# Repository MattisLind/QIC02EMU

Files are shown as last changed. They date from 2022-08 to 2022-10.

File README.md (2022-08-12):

# QIC02EMU

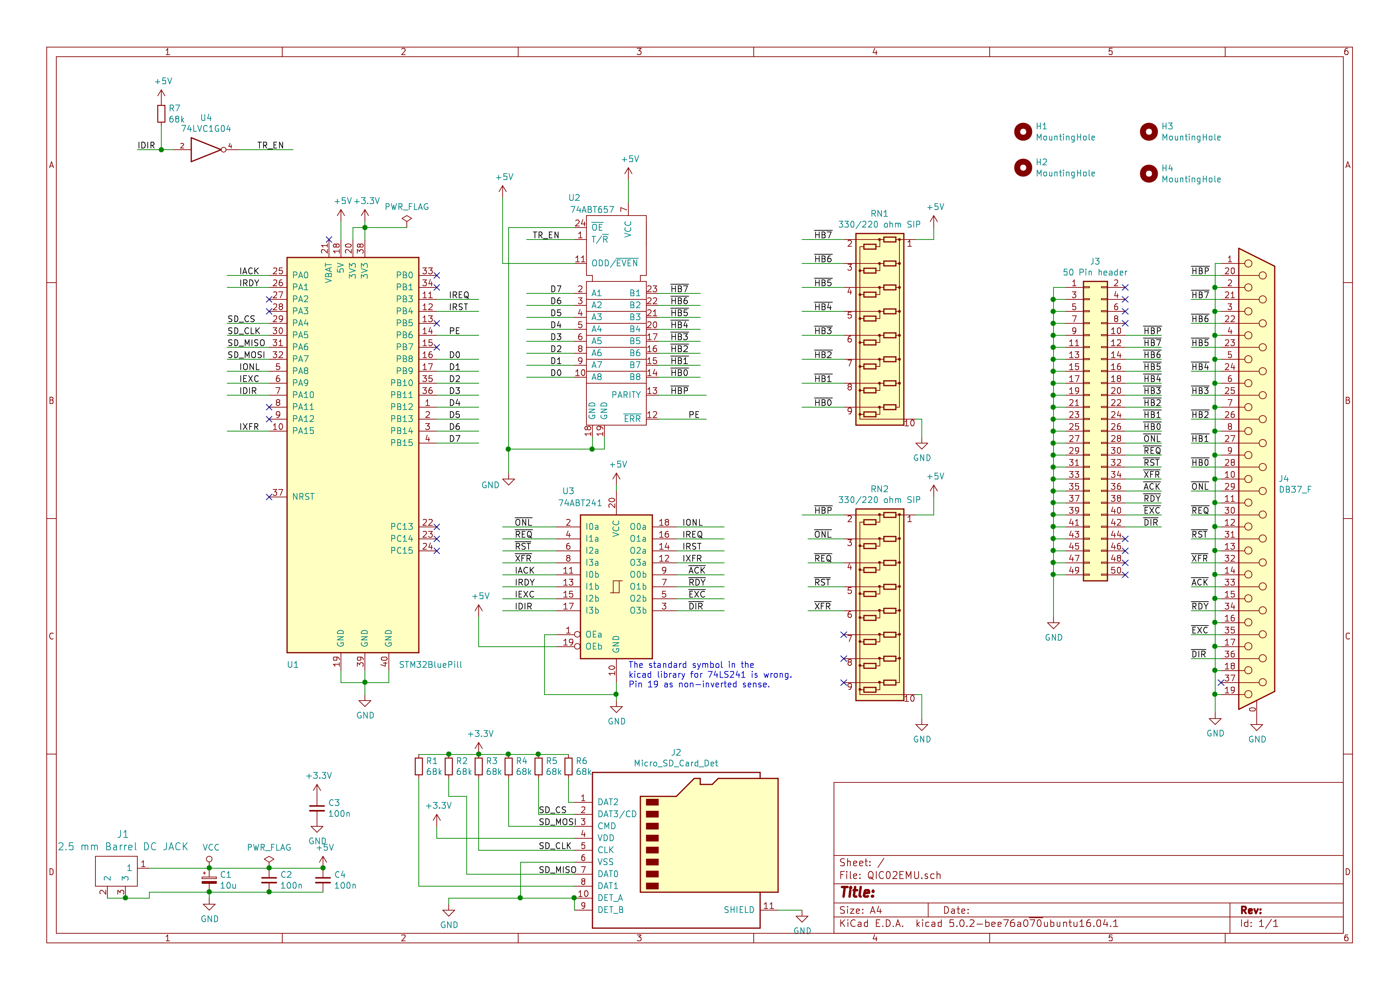
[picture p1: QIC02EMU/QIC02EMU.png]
Schematic


Device that is supposed to emulate a generic QIC-02 tape drive or specifically the IBM6157 tape drive. The IBM 6157 contains a Cipher 450 tape drive. But has a 37 pin DUSB interface cable rather than the 50 pin IDC type connector.

The card is supposed to plug directly into the IBM RT PC 6157 streaming tape controller board without using any cable.

Initially only reading of tape will be supported but later on writing will be implemented.

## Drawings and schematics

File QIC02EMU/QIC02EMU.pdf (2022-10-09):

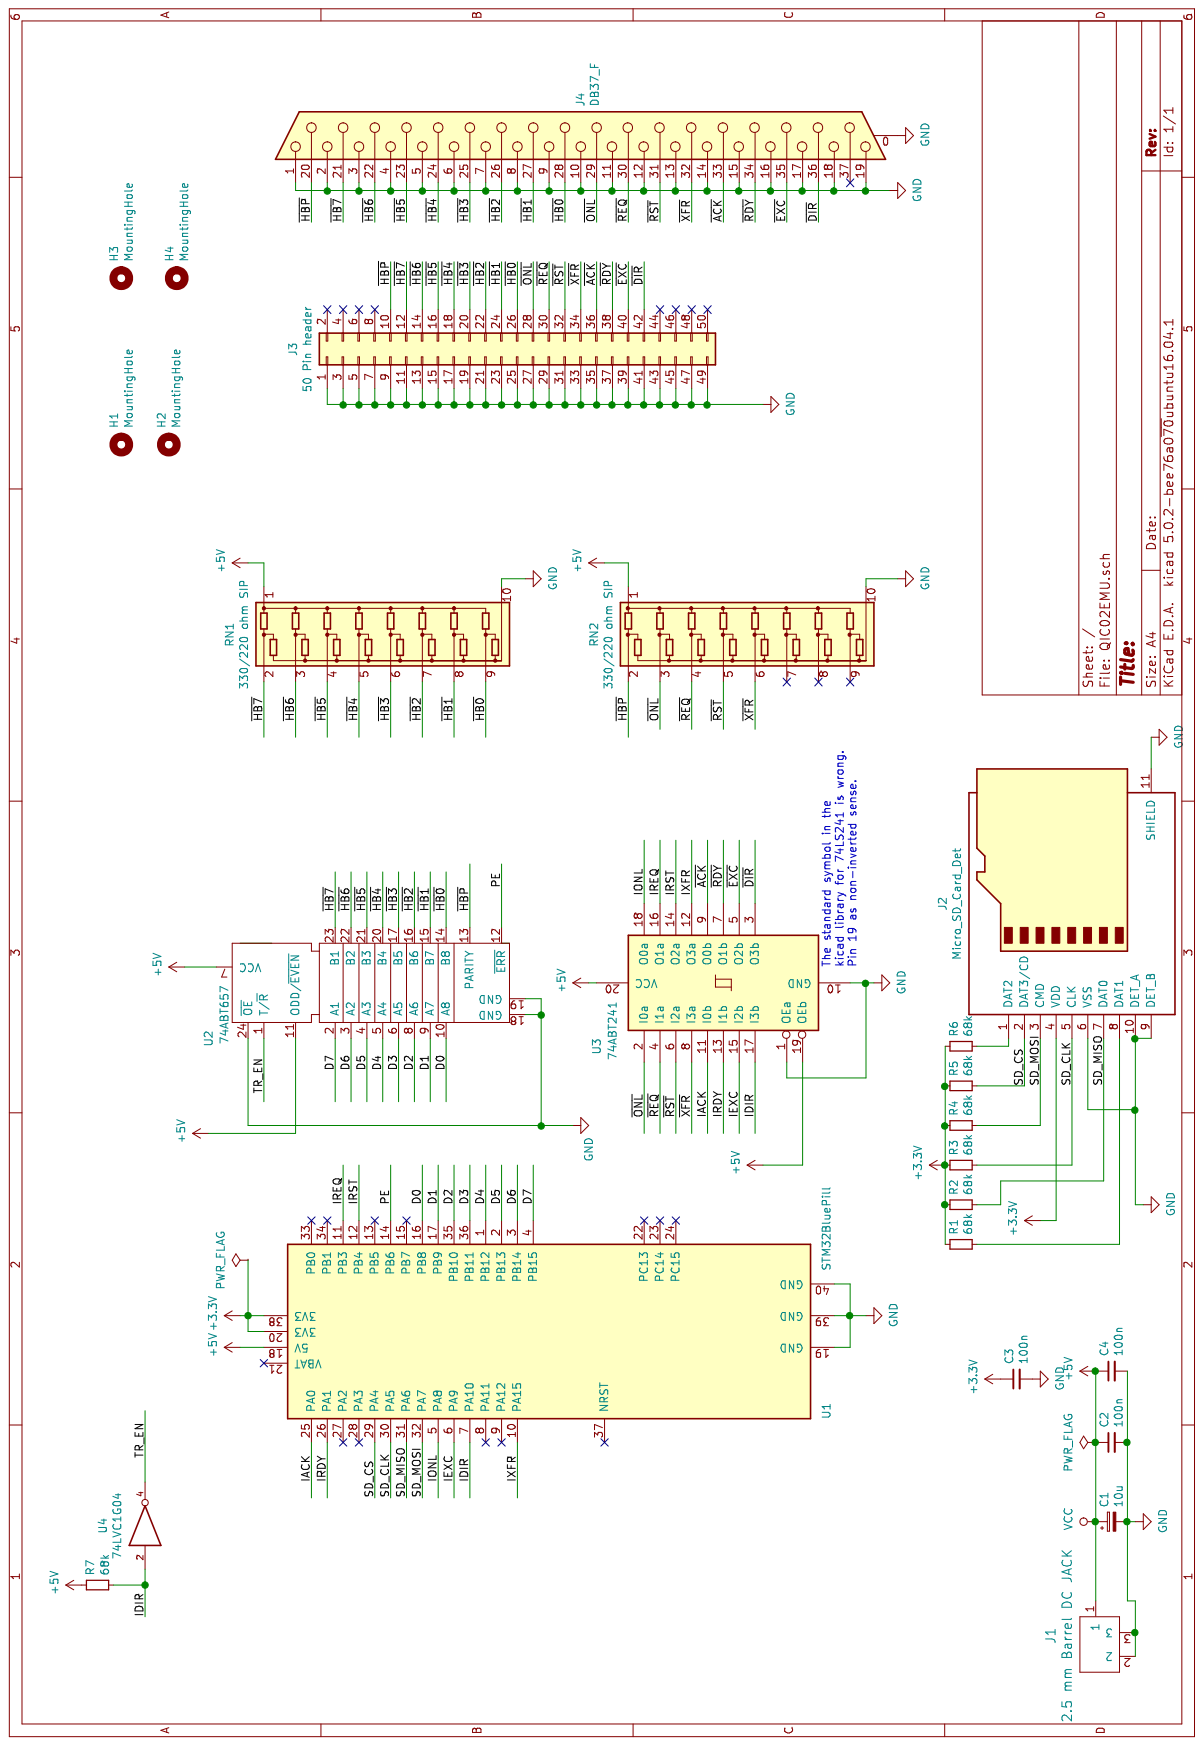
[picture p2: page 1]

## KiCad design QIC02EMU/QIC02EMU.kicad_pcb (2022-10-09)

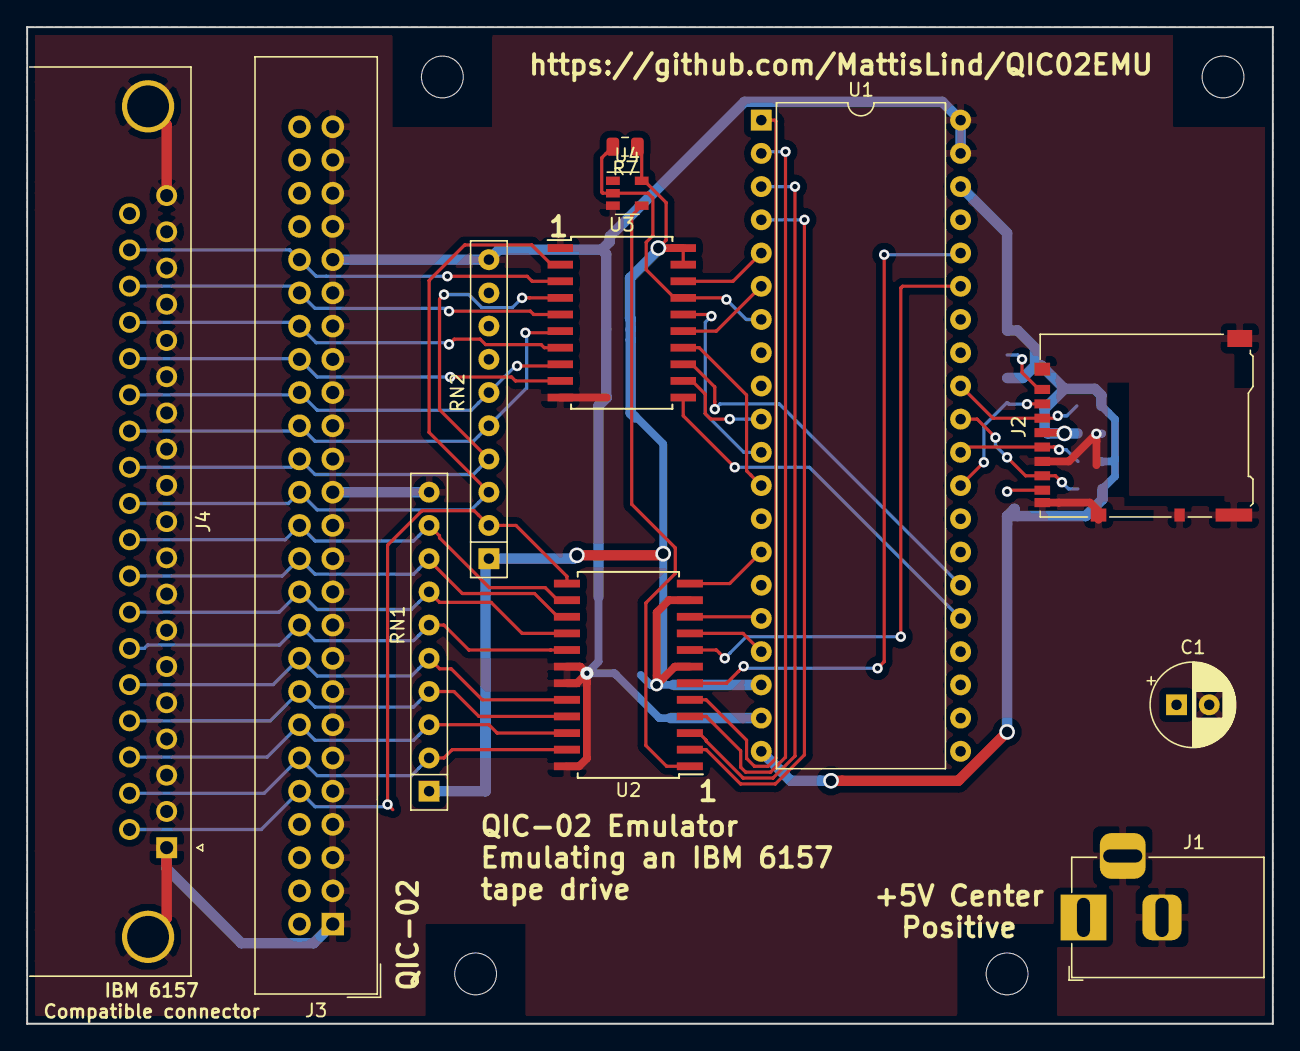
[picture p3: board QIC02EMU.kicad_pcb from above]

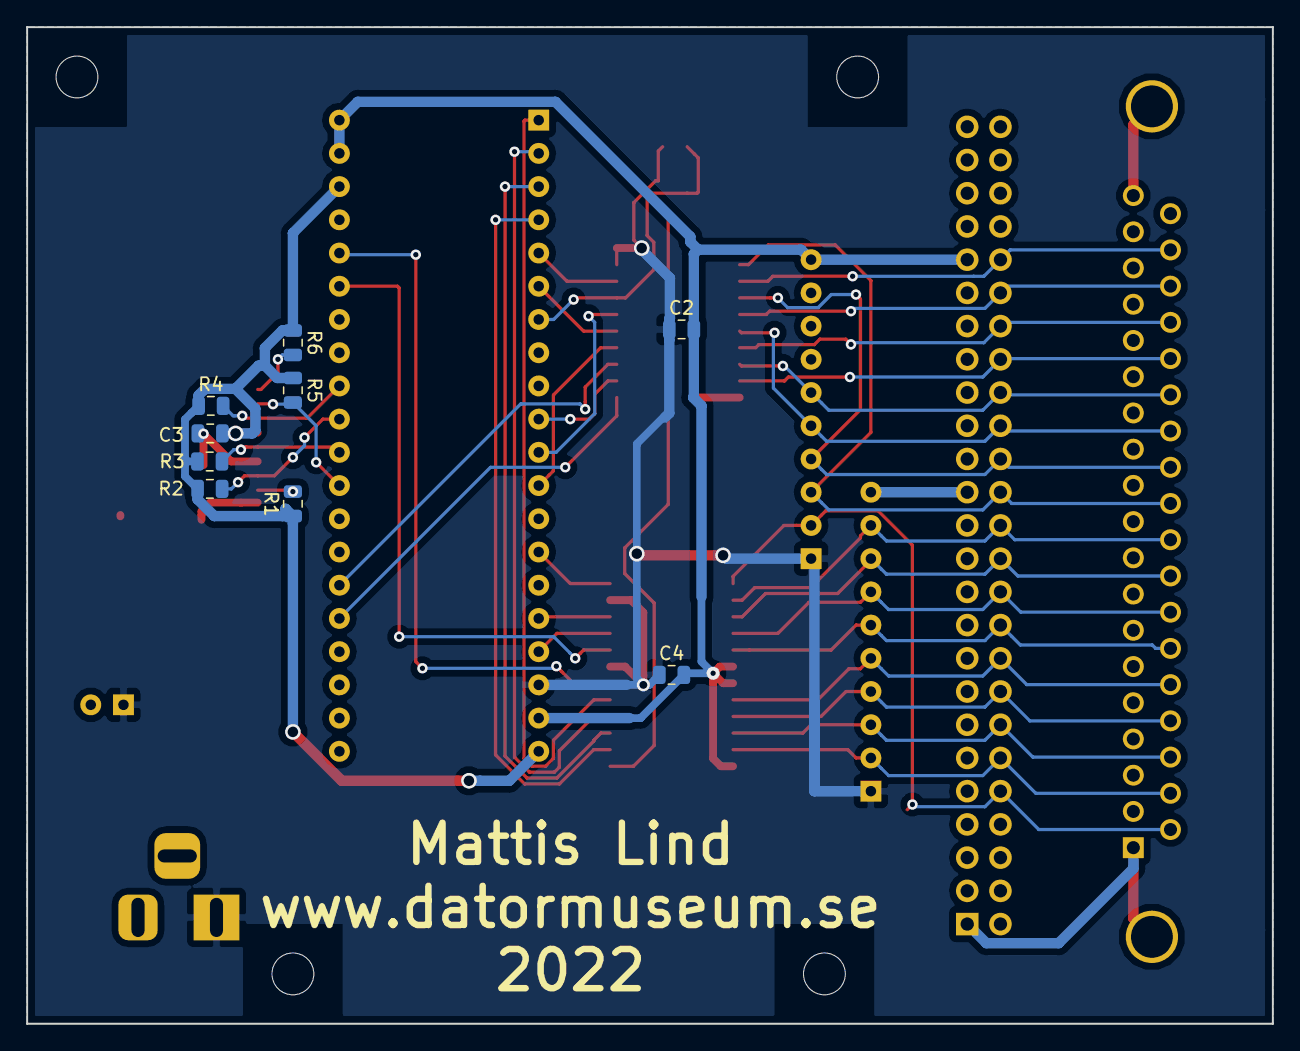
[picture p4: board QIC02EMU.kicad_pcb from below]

Board: 2 copper layers, 95.2 x 76.2 mm, 25 parts (9 on the bottom side), 44 nets.

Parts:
C1: 10u; CP_Radial_D6.3mm_P2.50mm
C2, C3, C4: 100n; C_0805_2012Metric
H1, H2, H3, H4: MountingHole; MountingHole_3.2mm_M3_ISO14580
J1: 2.5 mm Barrel DC JACK; BarrelJack_Horizontal
J2: Micro_SD_Card_Det; microSD_HC_Hirose_DM3AT-SF-PEJM5
J3: 50 Pin header; IDC-Header_2x25_P2.54mm_Vertical
J4: DB37_F; DSUB-37_Female_Horizontal_P2.77x2.84mm_EdgePinOffset7.70mm_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
R1, R2, R3, R4, R5, R6, R7: 68k; R_0805_2012Metric
RN1, RN2: 330/220 ohm SIP; R_Array_SIP10
U1: STM32BluePill; DIP-40_W15.24mm
U2: 74ABT657; SOIC-24W_7.5x15.4mm_P1.27mm
U3: 74ABT241; SOIC-20W_7.5x12.8mm_P1.27mm
U4: 74LVC1G04; SOT-23-5

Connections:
+3V3: C3.1, J2.4, R1.1, R2.1, R3.1, R4.1, R5.1, R6.1, U1.20, U1.38
+5V: C1.1, C2.1, C4.1, J1.1, R7.1, RN1.1, RN2.1, U1.18, U2.7, U2.11, U3.19, U3.20, U4.5
/D0: U1.16, U2.10
/D1: U1.17, U2.9
/D2: U1.35, U2.8
/D3: U1.36, U2.6
/D4: U1.1, U2.5
/D5: U1.2, U2.4
/D6: U1.3, U2.3
/D7: U1.4, U2.2
/IACK: U1.25, U3.11
/IDIR: R7.2, U1.7, U3.17, U4.2
/IEXC: U1.6, U3.15
/IONL: U1.5, U3.18
/IRDY: U1.26, U3.13
/IREQ: U1.11, U3.16
/IRST: U1.12, U3.14
/IXFR: U1.10, U3.12
/PE: U1.14, U2.12
/SD_CLK: J2.5, R3.2, U1.30
/SD_CS: J2.2, R5.2, U1.29
/SD_MISO: J2.7, R2.2, U1.31
/SD_MOSI: J2.3, R4.2, U1.32
/TR_EN: U2.1, U4.4
/~ACK: J3.36, J4.33, U3.9
/~DIR: J3.42, J4.36, U3.3
/~EXC: J3.40, J4.35, U3.5
/~HB0: J3.26, J4.28, RN1.9, U2.14
/~HB1: J3.24, J4.27, RN1.8, U2.15
/~HB2: J3.22, J4.26, RN1.7, U2.16
/~HB3: J3.20, J4.25, RN1.6, U2.17
/~HB4: J3.18, J4.24, RN1.5, U2.20
/~HB5: J3.16, J4.23, RN1.4, U2.21
/~HB6: J3.14, J4.22, RN1.3, U2.22
/~HB7: J3.12, J4.21, RN1.2, U2.23
/~HBP: J3.10, J4.20, RN2.2, U2.13
/~ONL: J3.28, J4.29, RN2.3, U3.2
/~RDY: J3.38, J4.34, U3.7
/~REQ: J3.30, J4.30, RN2.4, U3.4
/~RST: J3.32, J4.31, RN2.5, U3.6
/~XFR: J3.34, J4.32, RN2.6, U3.8
GND: C1.2, C2.2, C3.2, C4.2, J1.2, J1.3, J2.6, J2.9, J2.10, J2.11, J3.1, J3.3, J3.5, J3.7, J3.9, J3.11, J3.13, J3.15, J3.17, J3.19, J3.21, J3.23, J3.25, J3.27, J3.29, J3.31, J3.33, J3.35, J3.37, J3.39, J3.41, J3.43, J3.45, J3.47, J3.49, J4.0, J4.1, J4.2, J4.3, J4.4, J4.5, J4.6, J4.7, J4.8, J4.9, J4.10, J4.11, J4.12, J4.13, J4.14, J4.15, J4.16, J4.17, J4.18, J4.19, RN1.10, RN2.10, U1.19, U1.39, U1.40, U2.18, U2.19, U2.24, U3.1, U3.10, U4.3
unnamed: J2.1, R6.2
unnamed: J2.8, R1.2

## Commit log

2022-08-11 First draft.
    [QIC02EMU-B.Cu.gbr, QIC02EMU-B.Mask.gbr, QIC02EMU-B.Paste.gbr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]
2022-08-11 Added zip of all gerbers.
2022-08-12 Fixed a problem with the direction and one enable of the 241.
    [QIC02EMU-B.Cu.gbr, QIC02EMU-B.Mask.gbr, QIC02EMU-B.Paste.gbr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]
2022-08-15 Update with inverter.
    [QIC02EMU-B.Cu.gbr, QIC02EMU-B.Mask.gbr, QIC02EMU-B.Paste.gbr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]
2022-10-09 Fixed VDD/VSS issue on SD card.
    [QIC02EMU-B.Cu.gbr, QIC02EMU-B.Mask.gbr, QIC02EMU-B.Paste.gbr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]
